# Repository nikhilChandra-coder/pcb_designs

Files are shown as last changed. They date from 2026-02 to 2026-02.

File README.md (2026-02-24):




https://github.com/user-attachments/assets/6a94432a-129a-44d5-ad45-ea5ea002c121

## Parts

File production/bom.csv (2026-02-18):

Designator | Footprint | Quantity | Value
C1, C12, C4, C5 | 0603 | 4 | 10uF
C10, C13, C14, C6, C7, C8 | 0603 | 6 | 100nF
C11 | 0603 | 1 | 10nf
C15, C16, C17, C18 | 0603 | 4 | 1uF
C2 | 0603 | 1 | 470pF
C3 | 0805 | 1 | 2.2uF
C9 | 0603 | 1 | 2.2nf
D1 | D_SMA | 1 | SS34
D2, D3, D4, D5 | D_SOD-123F | 4 | 1N4148W
IC1 | SOIC127P600X175-9N | 1 | TP4056
J1 | USB_C_Receptacle_HRO_TYPE-C-31-M-12 | 1 | USB_C_Receptacle_USB2.0
J14 | CONN-TH_1.25T-2A_1.25T-2A | 1 | Conn_01x02
J2 | CONN-TH_2P-P2.50_XH-2AW | 1 | JST XH 2P 2.50mm SMD Hoz
LED1, LED2, LED5 | 0603 | 3 | LED_Red
LED3, LED6 | 0603 | 2 | LED_Blue
LED4 | 0603 | 1 | LED_Green
R1, R2 | 0603 | 2 | 5.1K
R10, R11, R12, R13, R6, R7, R9 | 0603 | 7 | 1K
R14, R16, R17, R18, R19, R20, R21, R22, R23, R24, R25 | 0603 | 11 | 10k
R15 | 0603 | 1 | 4.7k
R26, R27, R3, R8 | 0603 | 4 | 100K
R4 | 0603 | 1 | 470R
R5 | 0603 | 1 | 1.2K
SW1 | SW-SMD_MST22D18G2 | 1 | MST22D18G2_125
SW2, SW3 | Tactile 3x4x2mm TS-A010 | 2 | Tactile Switch 3x4x2
T1, T2, T3, T4 | SOT95P237X112-3N | 4 | IRLML6344TRPBF
U1 | SOT-23 | 1 | AO3401A
U2 | SOT-23-5 | 1 | SPX3819M5-L-3-3/TR
U5 | ESSOP-10_3.9x4.9mm_P1.00mm | 1 | CH340K
U6 | SOT-363_SC-70-6 | 1 | 2N27002DW
U8 | ESP32-S3-WROOM-1 | 1 | ESP32-S3-WROOM-1

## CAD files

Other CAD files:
LiteWingV2.5C-without-jst-B_Silkscreen.dxf
LiteWingV2.5C-without-jst-F_Silkscreen.dxf

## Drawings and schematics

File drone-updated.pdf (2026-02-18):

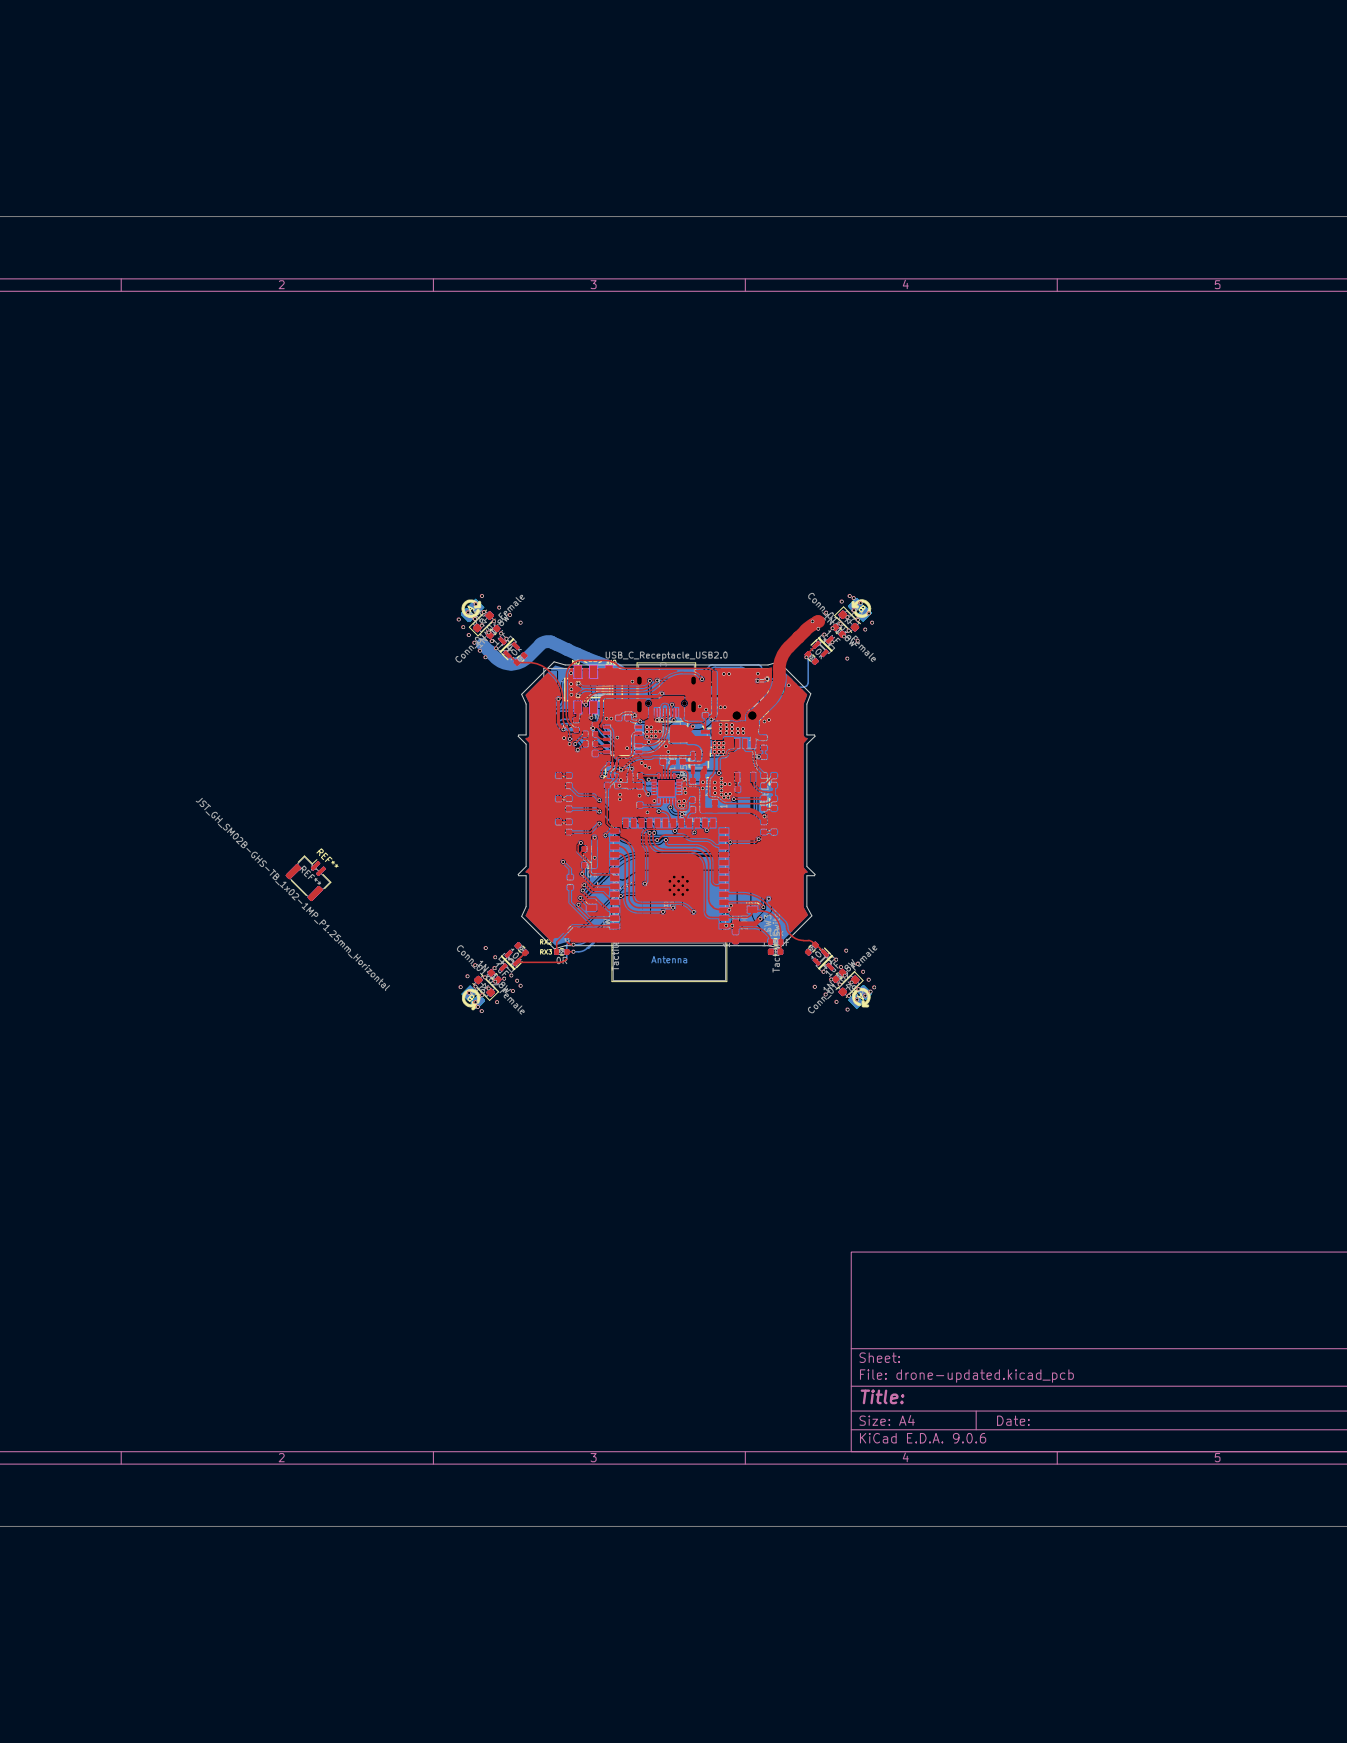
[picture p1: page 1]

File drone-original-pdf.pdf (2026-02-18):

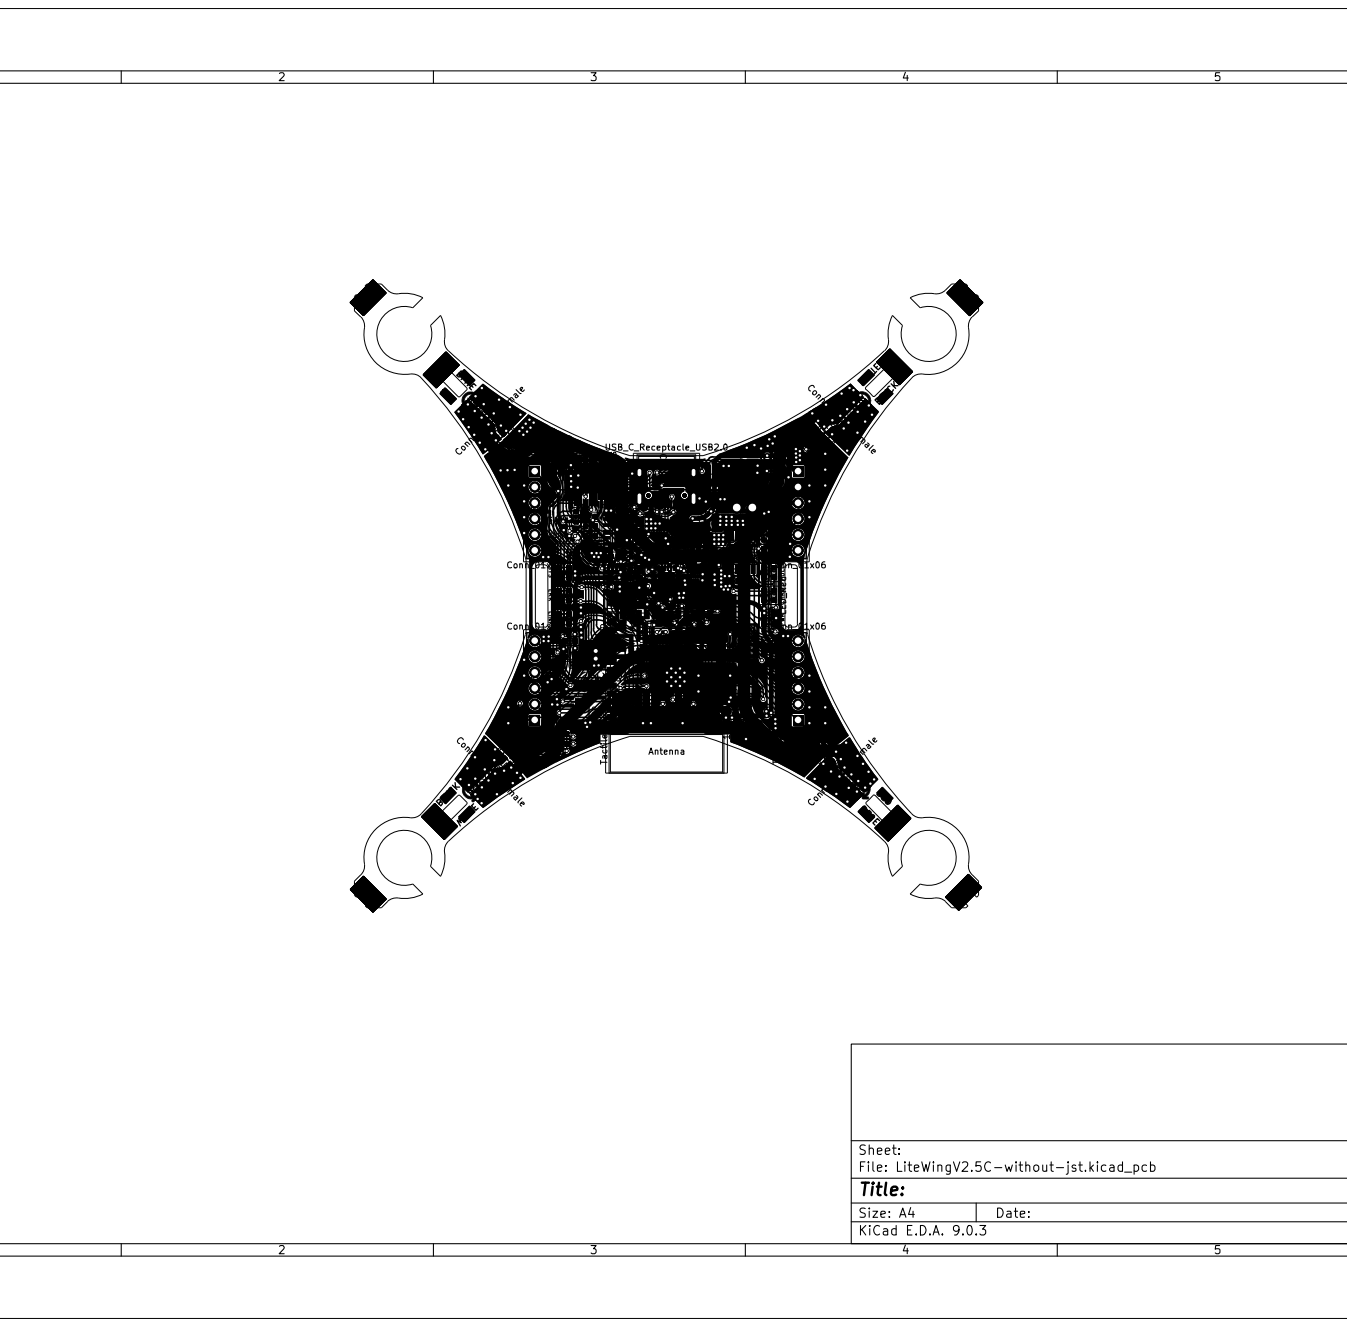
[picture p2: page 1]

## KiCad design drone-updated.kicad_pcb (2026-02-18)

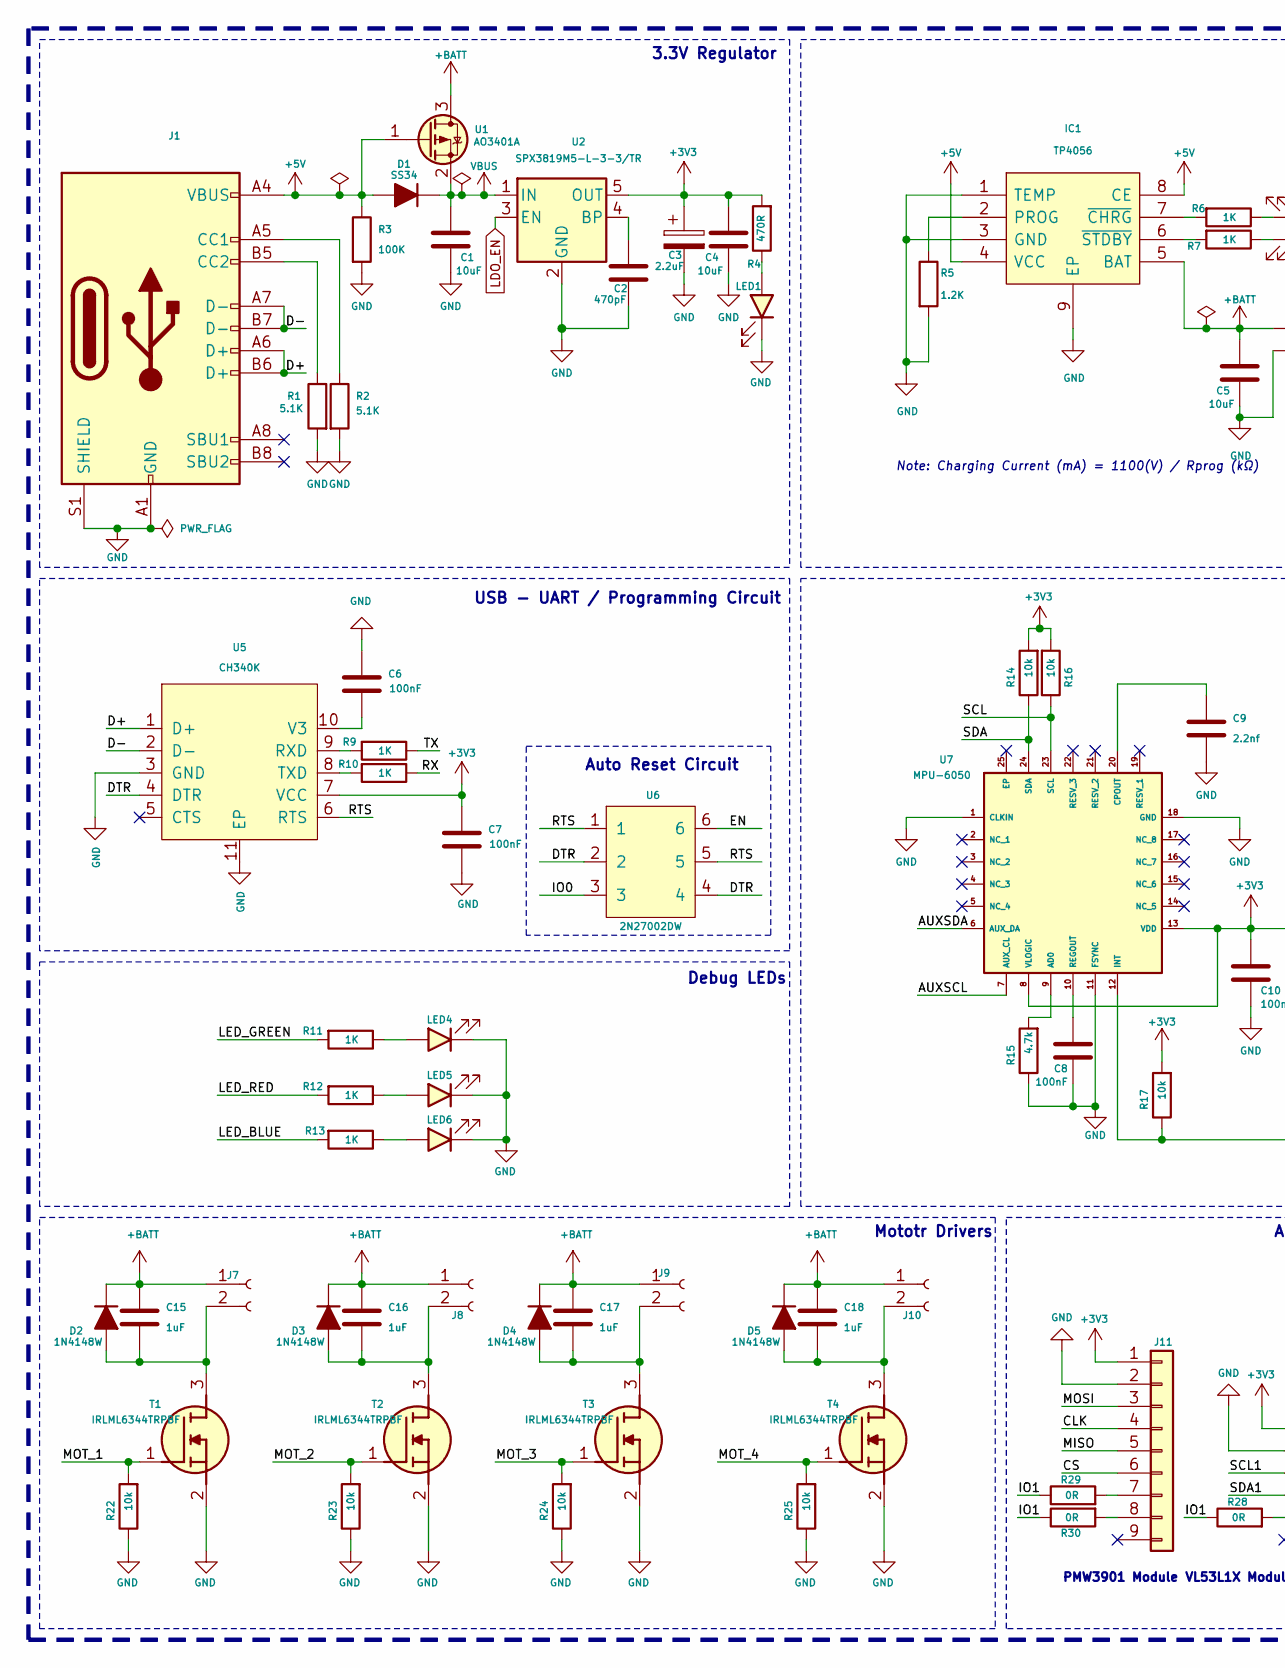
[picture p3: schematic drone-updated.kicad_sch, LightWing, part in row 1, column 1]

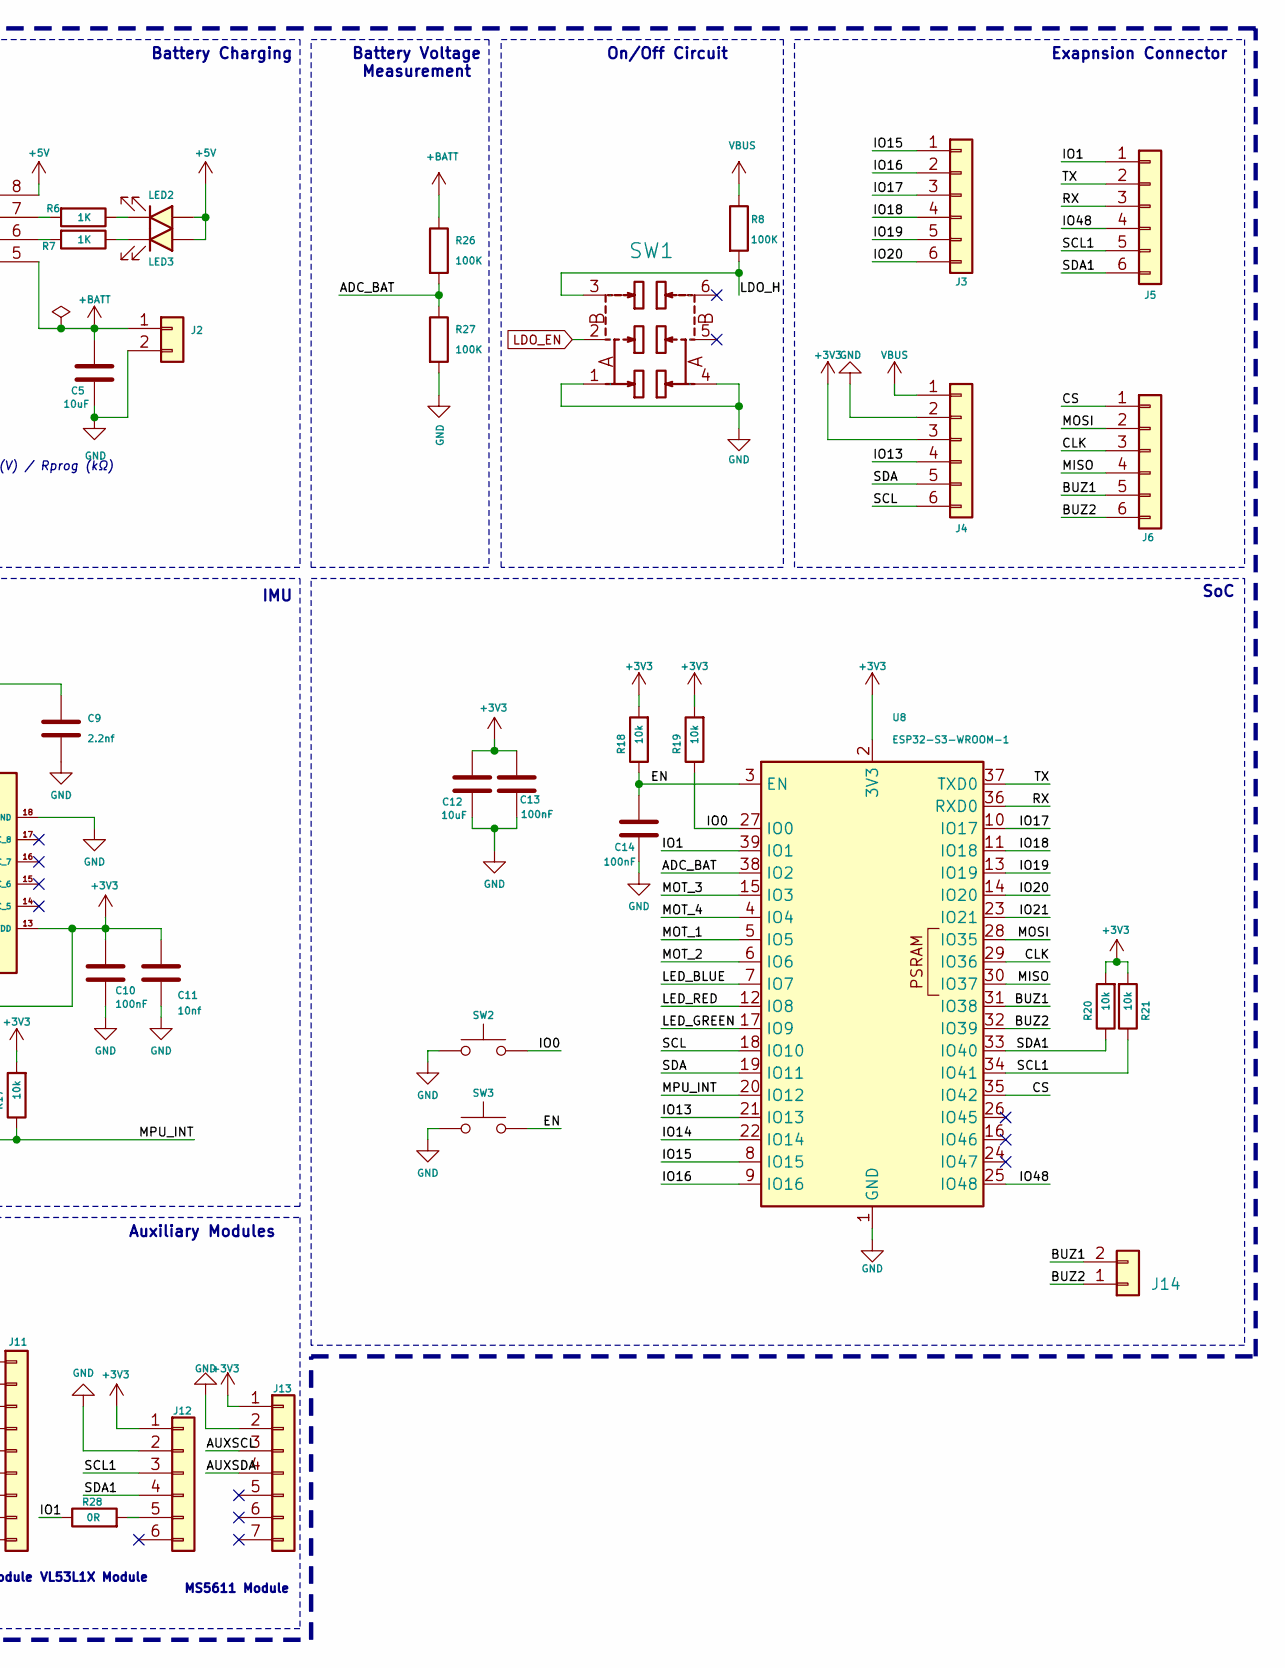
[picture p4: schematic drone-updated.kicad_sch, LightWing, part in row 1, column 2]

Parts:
C1, C4, C5, C12: 10uF; C_0603_1608Metric; MFR.Part # CL10A106KP8NNNC; LCSC Part # C19702
C2: 470pF; C_0603_1608Metric; MFR.Part # 0603B471K500NT; LCSC Part # C1620
C3: 2.2uF; C_0805_2012Metric; MFR.Part # TCC0805X7R225M250FT; LCSC Part # C5448893
C6, C7, C8, C10, C13, C14: 100nF; C_0603_1608Metric; MFR.Part # CC0603KRX7R9BB104; LCSC Part # C14663
C9: 2.2nf; C_0603_1608Metric; MFR.Part # 0603B222K500NT; LCSC Part # C1604
C11: 10nf; C_0603_1608Metric; MFR.Part # 0603B103K500NT; LCSC Part # C57112
C15, C16, C17, C18: 1uF; C_0603_1608Metric; MFR.Part # CL10A105KB8NNNC; LCSC Part # C15849
D1: SS34; D_SMA; MFR.Part # SS34; LCSC Part # C8678
D2, D3, D4, D5: 1N4148W; D_SOD-123F; MFR.Part # 1N4148W; LCSC Part # C81598
IC1: TP4056; SOIC127P600X175-9N; MFR.Part # TP4056; LCSC Part # C20199357
J1: USB_C_Receptacle_USB2.0; USB_C_Receptacle_HRO_TYPE-C-31-M-12; MFR.Part # USB-TYPE-C-018; LCSC Part # C2927038
J2: JST XH 2P 2.50mm SMD Hoz; CONN-TH_2P-P2.50_XH-2AW; MFR.Part # XH-2AW; LCSC Part # C33132
J3, J4, J5, J6: Conn_01x06; PinHeader_1x06_P2.54mm_Vertical
J7, J8, J9, J10: Conn_01x02_Female; JST_PH_B2B-PH-K_1x02_P2.00mm_Vertical
J11: Conn_01x09; PMW3901
J12: Conn_01x06; VL53L1X_BREAKOUT
J13: Conn_01x07; MS5611_Module
J14: Conn_01x02; CONN-TH_1.25T-2A_1.25T-2A; MFR.Part # 1.25-2A; LCSC Part # C722594
LED1, LED2, LED5: LED_Red; LED_0603_1608Metric; MFR.Part # KT-0603R; LCSC Part # C2286
LED3, LED6: LED_Blue; LED_0603_1608Metric; MFR.Part # KT-0603B; LCSC Part # C2288
LED4: LED_Green; LED_0603_1608Metric; MFR.Part # LTST-C193TGKT-5A; LCSC Part # C12065
R1, R2: 5.1K; R_0603_1608Metric; MFR.Part # 0603WAF5101T5E; LCSC Part # C23186
R3, R8, R26, R27: 100K; R_0603_1608Metric; MFR.Part # 0603WAF1003T5E; LCSC Part # C25803
R4: 470R; R_0603_1608Metric; MFR.Part # 0603WAF4700T5E; LCSC Part # C23179
R5: 1.2K; R_0603_1608Metric; MFR.Part # 0603WAF1201T5E; LCSC Part # C22765
R6, R7, R9, R10, R11, R12, R13: 1K; R_0603_1608Metric; MFR.Part # 0603WAF1001T5E; LCSC Part # C21190
R14, R16, R17, R18, R19, R20, R21, R22, R23, R24, R25: 10k; R_0603_1608Metric; MFR.Part # 0603WAF1002T5E; LCSC Part # C25804
R15: 4.7k; R_0603_1608Metric; MFR.Part # 0603WAF4701T5E; LCSC Part # C23162
R28, R29, R30: 0R; R_0603_1608Metric; MFR.Part # 0603WAF0000T5E; LCSC Part # C21189
SW1: MST22D18G2_125; SW-SMD_MST22D18G2; MFR.Part # MST22D18G2 125; LCSC Part # C2906280
SW2, SW3: Tactile Switch 3x4x2; Tactile 3x4x2mm TS-A010; MFR.Part # TS-KG88C-ART25F; LCSC Part # C2874433
T1, T2, T3, T4: IRLML6344TRPBF; SOT95P237X112-3N; MFR.Part # IRLML6344TRPBF-HXY; LCSC Part # C6285738
U1: AO3401A; SOT-23; MFR.Part # AO3401A; LCSC Part # C15127
U2: SPX3819M5-L-3-3/TR; SOT-23-5; MFR.Part # SPX3819M5-L-3-3/TR; LCSC Part # C9055
U5: CH340K; ESSOP-10_3.9x4.9mm_P1.00mm; MFR.Part # CH340K; LCSC Part # C18208922
U6: 2N27002DW; SOT-363_SC-70-6; MFR.Part # 2N27002DW; LCSC Part # C5190214
U7: MPU-6050; MPU6050; MFR.Part # MPU-6050; LCSC Part # C24112
U8: ESP32-S3-WROOM-1; MFR.Part # ESP32-S3-WROOM-1-N8; LCSC Part # C2913198

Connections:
+3V3: C3.1, C4.1, C7.1, C10.1, C11.1, C12.1, C13.1, J4.3, J11.1, J12.1, J13.1, R4.2, R14.2, R16.2, R17.2, R18.2, R19.2, R20.2, R21.2, U2.5 (OUT), U5.7 (VCC), U7.8 (VLOGIC), U7.13 (VDD), U8.2 (3V3)
+5V: D1.2 (A), IC1.4 (VCC), IC1.8 (CE), J1.A4 (VBUS), J1.A9 (VBUS), J1.B4 (VBUS), J1.B9 (VBUS), LED2.2 (A), LED3.2 (A), R3.1, U1.1 (G)
+BATT: C5.1, C15.1, C16.1, C17.1, C18.1, D2.1 (K), D3.1 (K), D4.1 (K), D5.1 (K), IC1.5 (BAT), J2.1, J7.1, J8.1, J9.1, J10.1, R26.1, U1.3 (D)
/ADC_BAT: R26.2, R27.1, U8.38 (IO2)
/AUXSCL: J13.3, U7.7 (AUX_CL)
/AUXSDA: J13.4, U7.6 (AUX_DA)
/BUZ1: J6.5, J14.2, U8.31 (IO38)
/BUZ2: J6.6, J14.1, U8.32 (IO39)
/CLK: J6.3, J11.4, U8.29 (IO36)
/CS: J6.1, J11.6, U8.35 (IO42)
/D+: J1.A6 (D+), J1.B6 (D+), U5.1 (D+)
/D-: J1.A7 (D-), J1.B7 (D-), U5.2 (D-)
/DTR: U5.4 (DTR), U6.2, U6.4
/EN: C14.1, R18.1, SW3.2, U6.6, U8.3 (EN)
/IO0: R19.1, SW2.2, U6.3, U8.27 (IO0)
/IO1: J5.1, R28.1, R29.1, R30.1, U8.39 (IO1)
/IO13: J4.4, U8.21 (IO13)
/IO14: U8.22 (IO14)
/IO15: J3.1, U8.8 (IO15)
/IO16: J3.2, U8.9 (IO16)
/IO17: J3.3, U8.10 (IO17)
/IO18: J3.4, U8.11 (IO18)
/IO19: J3.5, U8.13 (IO19)
/IO20: J3.6, U8.14 (IO20)
/IO21: U8.23 (IO21)
/IO48: J5.4, U8.25 (IO48)
/LDO_H: R8.2, SW1.3
/LED_BLUE: R13.2, U8.7 (IO7)
/LED_GREEN: R11.2, U8.17 (IO9)
/LED_RED: R12.2, U8.12 (IO8)
/MISO: J6.4, J11.5, U8.30 (IO37)
/MOSI: J6.2, J11.3, U8.28 (IO35)
/MOT_1: R22.2, T1.1 (G), U8.5 (IO5)
/MOT_2: R23.2, T2.1 (G), U8.6 (IO6)
/MOT_3: R24.2, T3.1 (G), U8.15 (IO3)
/MOT_4: R25.2, T4.1 (G), U8.4 (IO4)
/MPU_INT: R17.1, U7.12 (INT), U8.20 (IO12)
/RTS: U5.6 (RTS), U6.1, U6.5
/RX: J5.3, R10.1, U8.36 (RXD0)
/SCL: J4.6, R16.1, U7.23 (SCL), U8.18 (IO10)
/SCL1: J5.5, J12.3, R21.1, U8.34 (IO41)
/SDA: J4.5, R14.1, U7.24 (SDA), U8.19 (IO11)
/SDA1: J5.6, J12.4, R20.1, U8.33 (IO40)
/TX: J5.2, R9.1, U8.37 (TXD0)
GND: C1.2, C2.2, C3.2, C4.2, C5.2, C6.1, C7.2, C8.2, C9.2, C10.2, C11.2, C12.2, C13.2, C14.2, IC1.1 (TEMP), IC1.3 (GND), IC1.9 (EP), J1.A1 (GND), J1.A12 (GND), J1.B1 (GND), J1.B12 (GND), J1.S1 (SHIELD), J2.2, J4.2, J11.2, J12.2, J13.2, LED1.1 (K), LED4.1 (K), LED5.1 (K), LED6.1 (K), R1.2, R2.2, R3.2, R5.2, R15.1, R22.1, R23.1, R24.1, R25.1, R27.2, SW1.1, SW1.4, SW2.1, SW3.1, T1.2 (S), T2.2 (S), T3.2 (S), T4.2 (S), U2.2 (GND), U5.3 (GND), U5.11 (EP), U7.1 (CLKIN), U7.11 (FSYNC), U7.18 (GND), U8.1 (GND), U8.40 (GND), U8.41 (GND)
LDO_EN: SW1.2, U2.3 (EN)
unnamed: C15.2, D2.2 (A), J7.2, T1.3 (D)
unnamed: C16.2, D3.2 (A), J8.2, T2.3 (D)
unnamed: C17.2, D4.2 (A), J9.2, T3.3 (D)
unnamed: C18.2, D5.2 (A), J10.2, T4.3 (D)
unnamed: IC1.2 (PROG), R5.1
unnamed: IC1.7 (~CHRG), R6.2
unnamed: IC1.6 (~STDBY), R7.2
unnamed: J1.A5 (CC1), R2.1
unnamed: J1.B5 (CC2), R1.1
unnamed: J11.7, R29.2
unnamed: J11.8, R30.2
unnamed: J12.5, R28.2
unnamed: LED1.2 (A), R4.1
unnamed: LED2.1 (K), R6.1
unnamed: LED3.1 (K), R7.1
unnamed: LED4.2 (A), R11.1
unnamed: LED5.2 (A), R12.1
unnamed: LED6.2 (A), R13.1
unnamed: C2.1, U2.4 (BP)
unnamed: R9.2, U5.9 (RXD)
unnamed: R10.2, U5.8 (TXD)
unnamed: C6.2, U5.10 (V3)
unnamed: R15.2, U7.9 (AD0)
unnamed: C9.1, U7.20 (CPOUT)
unnamed: C8.1, U7.10 (REGOUT)
VBUS: C1.1, D1.1 (K), J4.1, R8.1, U1.2 (S), U2.1 (IN)

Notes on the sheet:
Note: Charging Current (mA) = 1100(V) / Rprog (kΩ)
IMU
VL53L1X Module
Debug LEDs
Battery Charging
3.3V Regulator
Battery Voltage Measurement
Auto Reset Circuit
USB - UART / Programming Circuit
SoC
Mototr Drivers
MS5611 Module
Exapnsion Connector
Auxiliary Modules
On/Off Circuit
PMW3901 Module

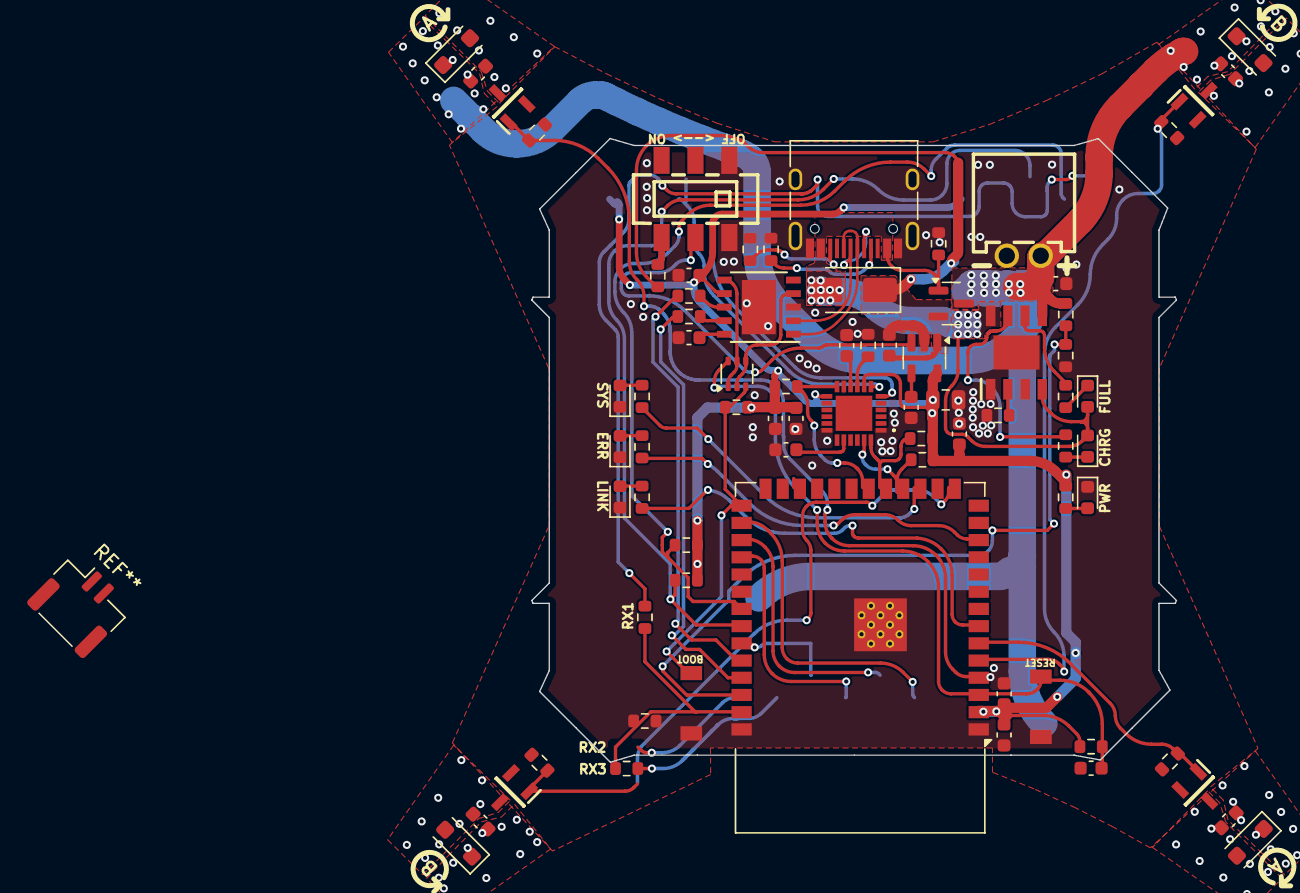
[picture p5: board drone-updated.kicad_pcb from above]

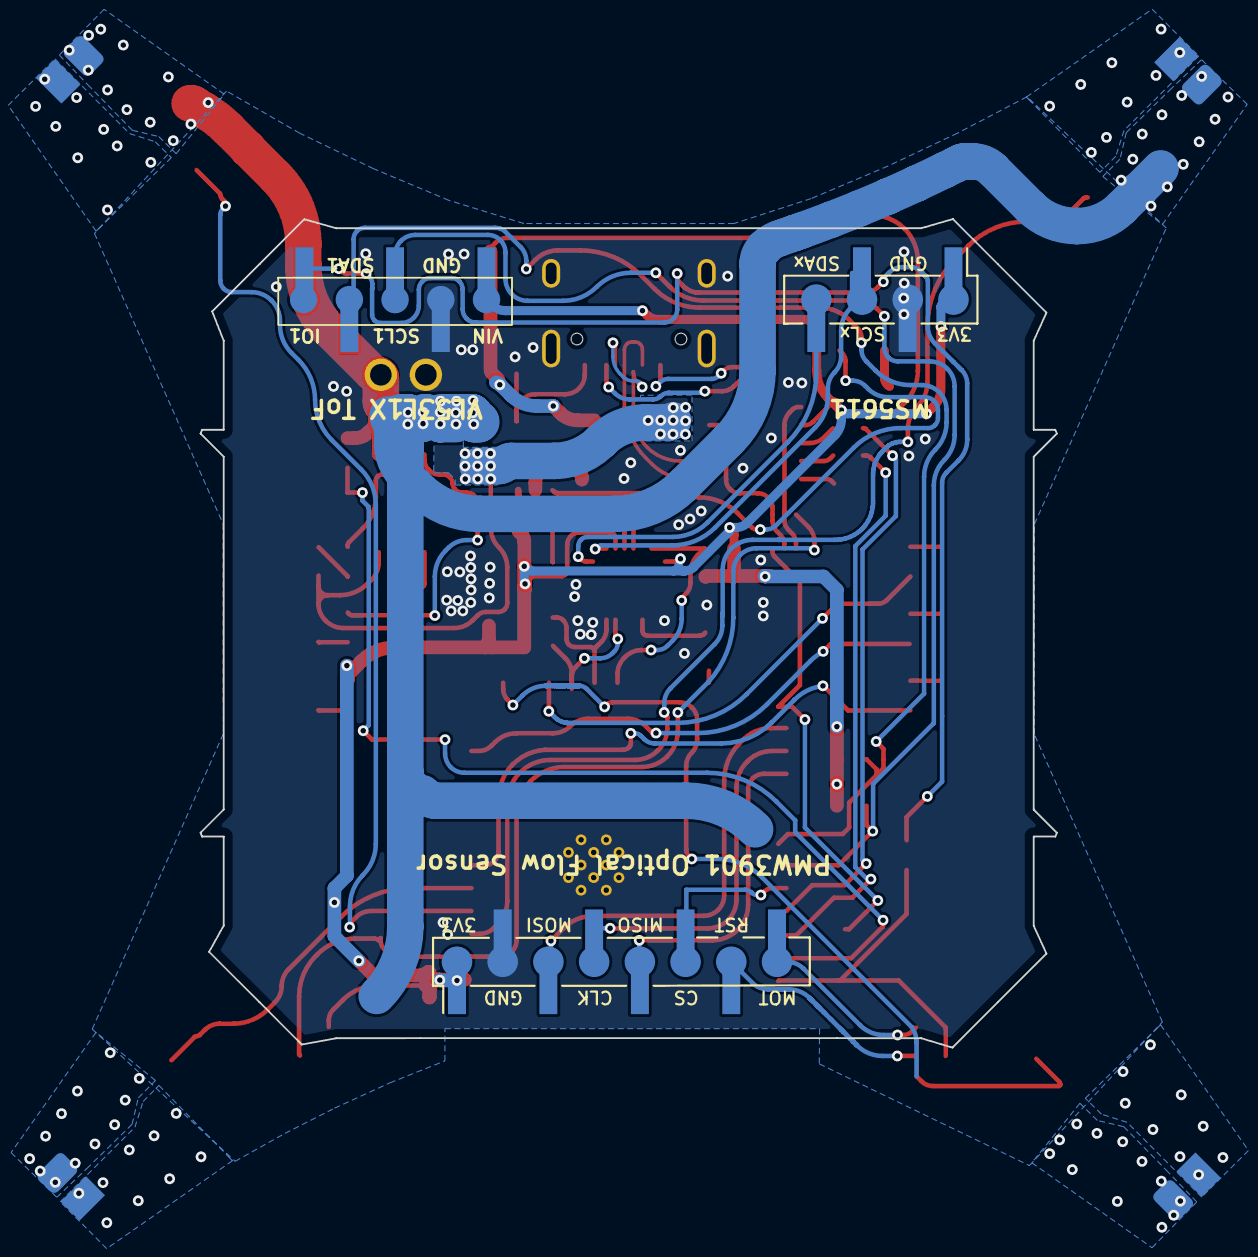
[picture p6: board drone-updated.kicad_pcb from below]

Board: 2 copper layers, 82 parts (3 on the bottom side), 60 nets.

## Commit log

2026-02-18 Initial upload of folder
    [LiteWingV2.5C-without-jst-B_Silkscreen.dxf, LiteWingV2.5C-without-jst-F_Silkscreen.dxf, LiteWingV2.5C-without-jst.kicad_pcb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]
2026-02-18 Add KiCAD gitignore and clean repository
2026-02-19 Update .gitignore to exclude Gerbers folder
    Uncomment Gerbers folder exclusion from sync.
2026-02-24 Update README with demo video
    Added a new link to a demo video of the drone showing the drone powering on but not lifting off
